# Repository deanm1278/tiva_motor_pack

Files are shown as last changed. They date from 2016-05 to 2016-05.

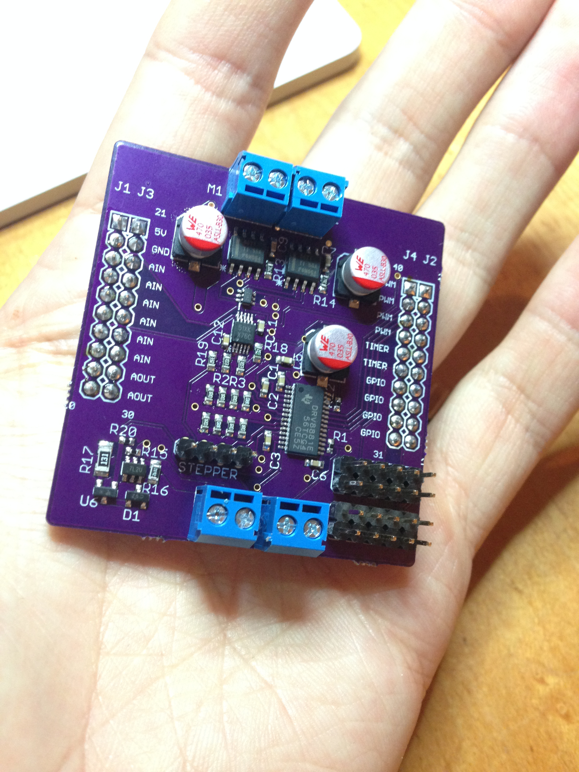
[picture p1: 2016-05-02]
tiva_motor.jpg

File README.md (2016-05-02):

# tiva_motor_pack
3 axis (2 servo 1 stepper) motor booster pack for EK-TM4C123GXL launchpad board

This booster pack drives 2 servos with encoders and 1 stepper motor.

The resolution limits are not yet well tested, but it definitely runs 2 brushed dc servos at 10khz velocity sampling and 1 stepper at 1/256 microstepping very smoothly. Stepper tested is a NEMA 17 2.0A at 2.8V motor that runs very smooth when microstepped. Servos tested are Harmonic drive RH-8 motors with Tamagawa encoders and also run well.

The software libraries include PID contol for the servos. Further tuning of PID may be necessary.

Servo drivers are TI DRV8871 (datasheet here: http://www.ti.com/lit/ds/symlink/drv8871.pdf)
stepper driver is a TI DRV8881E (datasheet here: http://www.ti.com/lit/ds/symlink/drv8881.pdf)

Autotune feature on the DRV8881E seems to work quite nicely :)

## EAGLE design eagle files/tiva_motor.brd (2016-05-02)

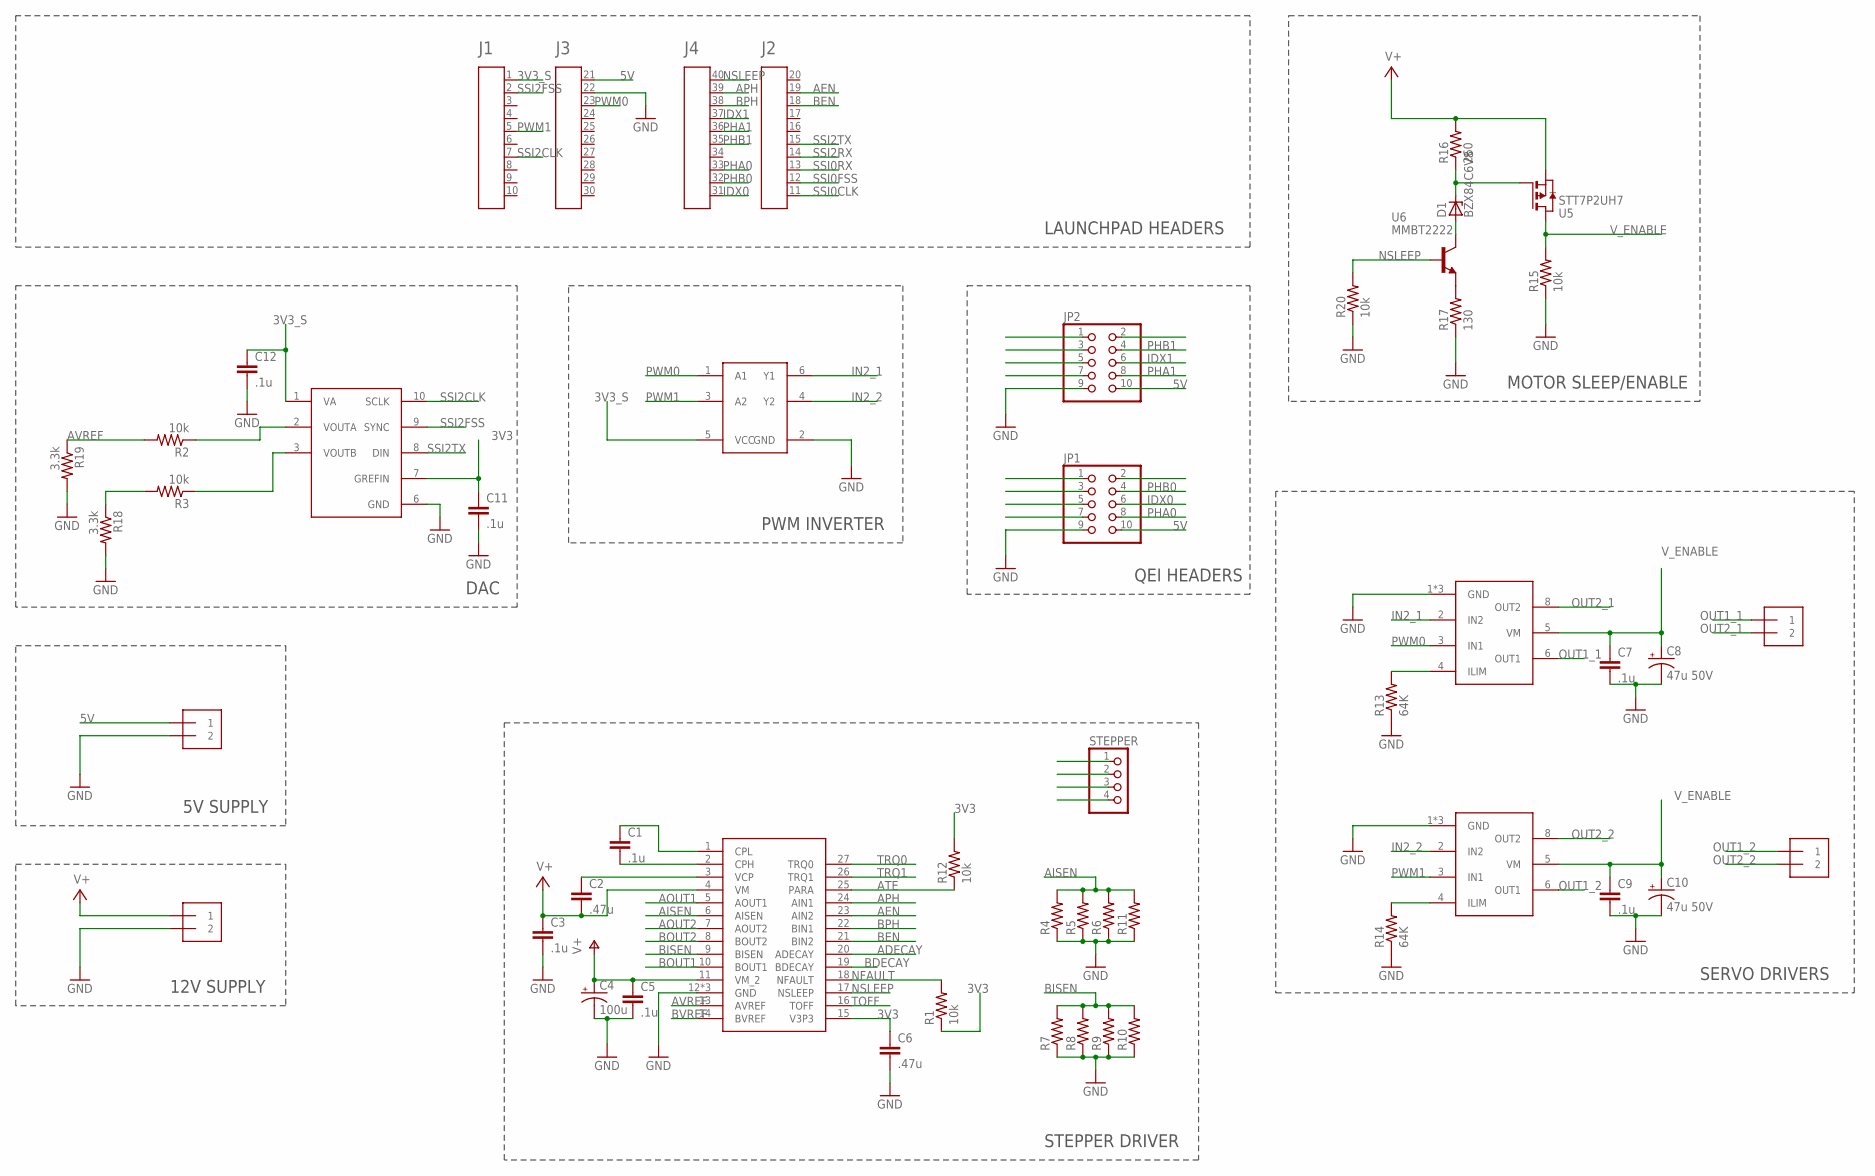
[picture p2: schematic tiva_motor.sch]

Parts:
5V, 12V: 1X2-3.5MM
A1: HEADER4X10-BOOSTERPACK; 4X10-BOOSTERPACK
C1, C3, C5, C7, C9: .1u; C0603
C2, C6: .47u; C0603
C4: 100u; 153CLV-0605
C8, C10: 47u 50V; 153CLV-0605
C11, C12: .1u; C0402
D1: BZX84C6V8; SOT-23
JP1, JP2: PINHD-2X5; 2X05
M1, M2: 1X2-3.5MM
R1, R12, R15, R20: 10k; R0402
R2, R3: 10k; R0603
R4, R5, R6, R7, R8, R9, R10, R11: R-US_R0603; R0603
R13, R14: 64K; R0603
R16: 260; R0805
R17: 130; R1206
R18, R19: 3.3k; R0603
STEPPER: PINHD-1X4; 1X04
U1: DRV8881; TSSOP28
U2, U4: DRV8871; SOIC127P600X170-9N
U5: STT7P2UH7; SOT23-6
U6: MMBT2222; SOT-23
U8: DAC082S085; SOP50P490X110-10N
U9: NC7WZ14; SC70-6

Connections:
3V3: C6.1, C11.1, R1.1, R12.2, U1.15 (V3P3), U8.7 (GREFIN)
3V3_S: A1.1, C12.1, U8.1 (VA), U9.5 (VCC)
5V: 5V.1, A1.21, JP1.10, JP2.10
ADECAY: U1.20 (ADECAY)
AEN: A1.19, U1.23 (AIN2)
AISEN: R4.2, R5.2, R6.2, R11.2, U1.6 (AISEN)
AOUT1: STEPPER.1, U1.5 (AOUT1)
AOUT2: STEPPER.2, U1.7 (AOUT2)
APH: A1.39, U1.24 (AIN1)
ATE: R12.1, U1.25 (PARA)
AVREF: R2.2, R19.1, U1.13 (AVREF)
BDECAY: U1.19 (BDECAY)
BEN: A1.18, U1.21 (BIN2)
BISEN: R7.2, R8.2, R9.2, R10.2, U1.9 (BISEN)
BOUT1: STEPPER.3, U1.10 (BOUT1)
BOUT2: STEPPER.4, U1.8 (BOUT2)
BPH: A1.38, U1.22 (BIN1)
BVREF: R3.2, R18.1, U1.14 (BVREF)
GND: 5V.2, 12V.2, A1.22, C3.2, C4.-, C5.2, C6.2, C7.2, C8.-, C9.2, C10.-, C11.2, C12.2, JP1.9, JP2.9, R4.1, R5.1, R6.1, R7.1, R8.1, R9.1, R10.1, R11.1, R13.1, R14.1, R15.1, R17.1, R18.2, R19.2, R20.1, U1.12 (GND), U1.28 (GND), U1.P$1 (GND), U2.1 (GND), U2.7 (GND), U2.9 (GND), U4.1 (GND), U4.7 (GND), U4.9 (GND), U8.6 (GND), U9.2 (GND)
IDX0: A1.31, JP1.6
IDX1: A1.37, JP2.6
ILIM: R13.2, U2.4 (ILIM)
ILIM1: R14.2, U4.4 (ILIM)
IN2_1: U2.2 (IN2), U9.6 (Y1)
IN2_2: U4.2 (IN2), U9.4 (Y2)
unnamed: C1.2, U1.2 (CPH)
unnamed: C1.1, U1.1 (CPL)
unnamed: C2.1, U1.3 (VCP)
unnamed: R17.2, U6.2 (E)
unnamed: D1.3 (C), R16.1, U5.3 (G)
unnamed: R2.1, U8.2 (VOUTA)
unnamed: R3.1, U8.3 (VOUTB)
unnamed: D1.1 (A), U6.3 (C)
NC: JP1.2
NFAULT: R1.2, U1.18 (NFAULT)
NSLEEP: A1.40, R20.2, U1.17 (NSLEEP), U6.1 (B)
OUT1_1: M1.1, U2.6 (OUT1)
OUT1_2: M2.1, U4.6 (OUT1)
OUT2_1: M1.2, U2.8 (OUT2)
OUT2_2: M2.2, U4.8 (OUT2)
PHA0: A1.33, JP1.8
PHA1: A1.36, JP2.8
PHB0: A1.32, JP1.4
PHB1: A1.35, JP2.4
PWM0: A1.23, U2.3 (IN1), U9.1 (A1)
PWM1: A1.5, U4.3 (IN1), U9.3 (A2)
SSI0CLK: A1.11
SSI0FSS: A1.12
SSI0RX: A1.13
SSI2CLK: A1.7, U8.10 (SCLK)
SSI2FSS: A1.2, U8.9 (SYNC)
SSI2RX: A1.14
SSI2TX: A1.15, U8.8 (DIN)
TOFF: U1.16 (TOFF)
TRQ0: U1.27 (TRQ0)
TRQ1: U1.26 (TRQ1)
V+: 12V.1, C2.2, C3.1, C4.+, C5.1, R16.2, U1.4 (VM), U1.11 (VM_2), U5.4 (S)
V_ENABLE: C7.1, C8.+, C9.1, C10.+, R15.2, U2.5 (VM), U4.5 (VM), U5.1 (D), U5.2 (D), U5.5 (D), U5.6 (D)

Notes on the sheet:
LAUNCHPAD HEADERS
DAC
5V SUPPLY
12V SUPPLY
PWM INVERTER
QEI HEADERS
MOTOR SLEEP/ENABLE
SERVO DRIVERS
STEPPER DRIVER

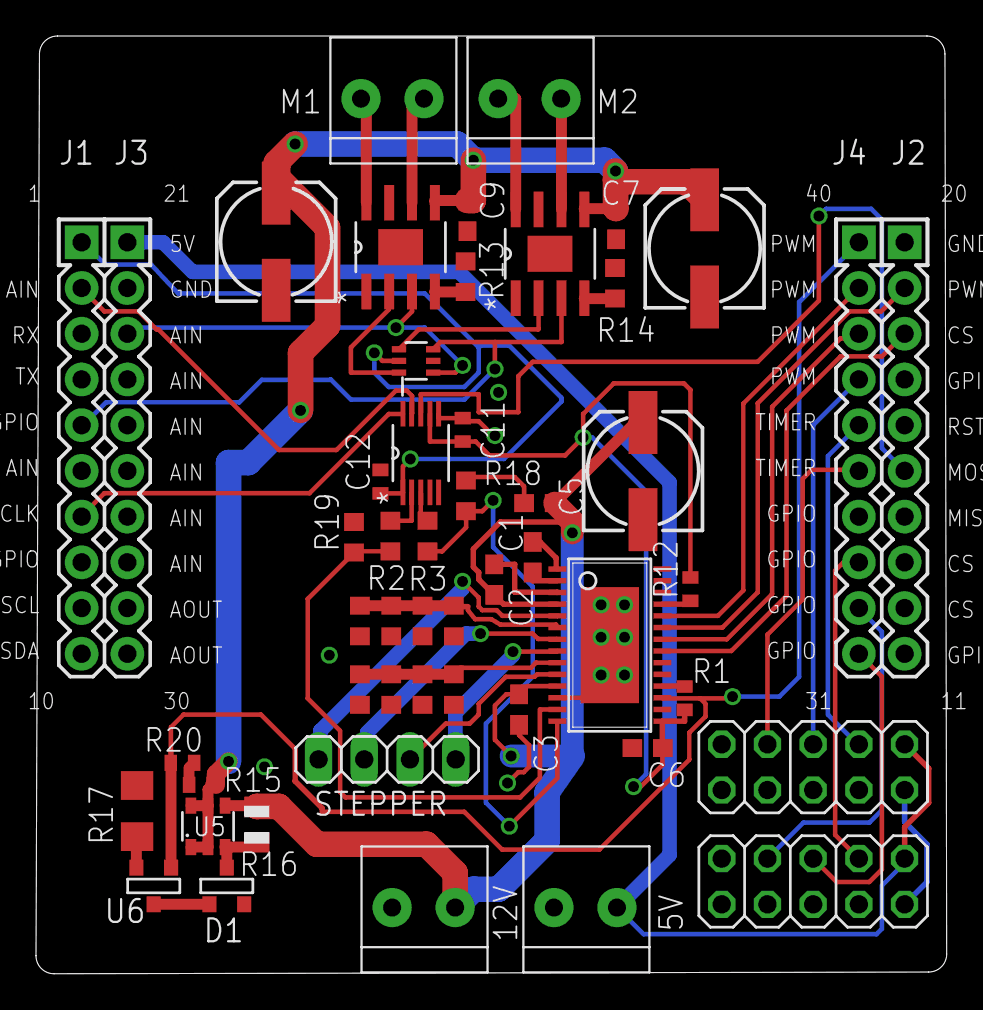
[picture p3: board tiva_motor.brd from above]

Board: 2 copper layers, 50.6 x 52.1 mm, 48 parts (0 on the bottom side), 48 nets.

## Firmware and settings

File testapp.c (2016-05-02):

#include <stdio.h>
#include <stdint.h>
#include <stdbool.h>

#include "inc/hw_memmap.h"

#include "driverlib/pin_map.h"
#include "driverlib/rom.h"
#include "driverlib/sysctl.h"

#include "libmotorpack/libmotorpack.h"

#define STEPS_PER_REV 200
#define SEC_PER_MIN 60

int main(void) {
	//
	// Enable lazy stacking for interrupt handlers.  This allows floating-point
	// instructions to be used within interrupt handlers, but at the expense of
	// extra stack usage.
	//
	ROM_FPULazyStackingEnable();
	ROM_FPUEnable();

	//
	// Set the clocking to run directly from the crystal.
	// Clock to 80MHZ
	//
	ROM_SysCtlClockSet(SYSCTL_SYSDIV_2_5 | SYSCTL_USE_PLL | SYSCTL_XTAL_16MHZ |
					   SYSCTL_OSC_MAIN);

	ROM_IntMasterEnable();

	//initialize the motor pack
	motor_pack_init();

	//initialize the stepper
	motor_pack_init_stepper();

	//set stepper to 20 rpm
	uint32_t rpm = 20;
	motor_pack_set_stepping_rate(rpm * STEPS_PER_REV / SEC_PER_MIN);

	//set to different speeds
	motor_pack_set_servo_speed(MP_SERVO1, -2.6);
	motor_pack_set_servo_speed(MP_SERVO2, 3);

	//initialize both servos
	motor_pack_init_servo(MP_SERVO1 | MP_SERVO2);

	//enable all drivers
	motor_pack_enable_motors();

	//start all motors
	motor_pack_stepper_start();
	motor_pack_servo_start(MP_SERVO1 | MP_SERVO2);

	//loop forever
	while(1){
	}

	return 0;
}

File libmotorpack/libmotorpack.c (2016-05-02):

/*
 * libmotorpack.c
 *
 *  Created on: May 1, 2016
 *      Author: Dean Miller
 */
#include <stdint.h>
#include <stdbool.h>
#include <math.h>

#include "inc/hw_ints.h"
#include "inc/hw_memmap.h"

#include "driverlib/pin_map.h"
#include "driverlib/gpio.h"
#include "driverlib/sysctl.h"
#include "driverlib/timer.h"
#include "driverlib/interrupt.h"
#include "driverlib/qei.h"
#include "driverlib/pwm.h"

#include "libmotorpack.h"
#include "stepper.h"
#include "servo.h"
#include "microstep_values.h"

static struct motor_pack mp;

//Define the QEI timer interrupts
void QEI0IntHandler(void){
	QEIIntClear(QEI0_BASE, QEI_INTTIMER);
	servo_read(&mp.servo1);

	servo_loop(&mp.servo1);
}

void QEI1IntHandler(void){
	QEIIntClear(QEI1_BASE, QEI_INTTIMER);
	servo_read(&mp.servo2);

	servo_loop(&mp.servo2);
}

//stepper interrupt handler
void
TIMER2IntHandler(void){
	//
	// Clear the timer interrupt.
	//
	TimerIntClear(TIMER2_BASE, TIMER_TIMA_TIMEOUT);
	uint32_t val = microstep_values[mp.step.t_val];

	if(val & MS_APH)	GPIOPinWrite(GPIO_PORTF_BASE, GPIO_PIN_3, GPIO_PIN_3);
	else	GPIOPinWrite(GPIO_PORTF_BASE, GPIO_PIN_3, 0x00);

	if(val & MS_BPH)	GPIOPinWrite(GPIO_PORTB_BASE, GPIO_PIN_3, GPIO_PIN_3);
	else	GPIOPinWrite(GPIO_PORTB_BASE, GPIO_PIN_3, 0x00);

	DAC082S085_set_value(&mp.step.dac, DAC082S085_DAC0, (val & MS_AVREF) >> 8);
	DAC082S085_set_value(&mp.step.dac, DAC082S085_DAC1, (val & MS_BVREF));

	mp.step.t_val += mp.step.div;
	mp.step.fires_this_move++;
	if(mp.step.t_val > 1023) mp.step.t_val = 0;
}

void motor_pack_init(){
	SysCtlPeripheralEnable(SYSCTL_PERIPH_GPIOF);

	GPIOPinTypeGPIOOutput(GPIO_PORTF_BASE, GPIO_PIN_2); //enable / disable for motors
	servo_init_pwm(&mp.servo1, PWM_OUT_0, PWM_PERIOD);
	servo_stop(&mp.servo1);

	servo_init_pwm(&mp.servo2, PWM_OUT_4, PWM_PERIOD);
	servo_stop(&mp.servo2);
}

void motor_pack_init_servo(uint32_t SERVO){
	if(SERVO & MP_SERVO1){
		servo_init_qei(&mp.servo1, QEI0_BASE);
	}
	if(SERVO & MP_SERVO2){
		servo_init_qei(&mp.servo2, QEI1_BASE);
	}
}

void motor_pack_set_servo_speed(uint32_t SERVO, float speed){
	int dir = 1;
	if(speed < 0){
		dir = -1;
		speed = fabs(speed);
	}
	if(SERVO & MP_SERVO1){
		mp.servo1.target_dir = dir;
		mp.servo1.target_speed = speed;
	}
	if(SERVO & MP_SERVO2){
		mp.servo2.target_dir = dir;
		mp.servo2.target_speed = speed;
	}
}

void motor_pack_servo_start(uint32_t SERVO){
	if(SERVO & MP_SERVO1){
		servo_start(&mp.servo1);
	}
	if(SERVO & MP_SERVO2){
		servo_start(&mp.servo2);
	}
}

void motor_pack_servo_stop(uint32_t SERVO){
	if(SERVO & MP_SERVO1){
		servo_stop(&mp.servo1);
	}
	if(SERVO & MP_SERVO2){
		servo_stop(&mp.servo2);
	}
}

void motor_pack_enable_motors(){
	GPIOPinWrite(GPIO_PORTF_BASE, GPIO_PIN_2, GPIO_PIN_2);
}

void motor_pack_disable_motors(){
	GPIOPinWrite(GPIO_PORTF_BASE, GPIO_PIN_2, 0);
}

void motor_pack_init_stepper(){
	stepper_init(&mp.step);
}

void motor_pack_set_stepper_div(uint32_t div){
	mp.step.div = div;
}

void motor_pack_set_stepping_rate(uint32_t stepping_rate){
	stepper_set_stepping_rate(&mp.step, stepping_rate);
}

void motor_pack_stepper_start(){
	stepper_start(&mp.step);
}

void motor_pack_stepper_stop(){
	stepper_stop(&mp.step);
}

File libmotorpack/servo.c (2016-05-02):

/*
 * servo.c
 *
 *  Created on: Jan 23, 2016
 *      Author: deanmiller
 */
#include <stdint.h>
#include <stdbool.h>
#include <string.h>
#include <stdlib.h>
#include <math.h>

#include "inc/hw_ints.h"
#include "inc/hw_memmap.h"
#include "inc/hw_types.h"
#include "inc/hw_gpio.h"

#include "driverlib/debug.h"
#include "driverlib/fpu.h"
#include "driverlib/gpio.h"
#include "driverlib/interrupt.h"
#include "driverlib/pin_map.h"
#include "driverlib/sysctl.h"
#include "driverlib/pwm.h"
#include "driverlib/qei.h"

#include "servo.h"
#include "pid.h"

extern void QEI0IntHandler(void);
extern void QEI1IntHandler(void);

void servo_init_pwm(struct servo *servo, uint32_t PWM_OUT, uint32_t PERIOD_HIGH)
{
	//TODO: make sure valid pwm base is passed in

	servo->PWM_PERIOD_HIGH = PERIOD_HIGH;
	servo->dc = PERIOD_HIGH / 2;
	servo->PWM_BASE = PWM0_BASE;
	servo->PWM_OUT = PWM_OUT;

	//set pwm clock to system clock
	SysCtlPWMClockSet(SYSCTL_PWMDIV_1);

	//already enabled
	SysCtlPeripheralEnable(SYSCTL_PERIPH_GPIOB);
	SysCtlPeripheralEnable(SYSCTL_PERIPH_GPIOE);

	SysCtlPeripheralEnable(SYSCTL_PERIPH_PWM0);
	//wait for peripheral to be ready
	while(!SysCtlPeripheralReady(SYSCTL_PERIPH_PWM0)){ }

	if(PWM_OUT == PWM_OUT_0){
		//configure for count down mode with immediate updates to params
		PWMGenConfigure(PWM0_BASE, PWM_GEN_0, PWM_GEN_MODE_DOWN | PWM_GEN_MODE_NO_SYNC);

		//set period
		PWMGenPeriodSet(PWM0_BASE, PWM_GEN_0, PWM_PERIOD);

		GPIOPinConfigure(GPIO_PB6_M0PWM0);

		GPIOPinTypePWM(GPIO_PORTB_BASE, GPIO_PIN_6);

		//enable outputs
		PWMOutputState(PWM0_BASE, PWM_OUT_0_BIT, true);

		//start timers in gen0
		PWMGenEnable(PWM0_BASE, PWM_GEN_0);
	}
	else if(PWM_OUT == PWM_OUT_4){
		//configure for count down mode with immediate updates to params
		PWMGenConfigure(PWM0_BASE, PWM_GEN_2, PWM_GEN_MODE_DOWN | PWM_GEN_MODE_NO_SYNC);

		//set period
		PWMGenPeriodSet(PWM0_BASE, PWM_GEN_2, PWM_PERIOD);

		GPIOPinConfigure(GPIO_PE4_M0PWM4);

		GPIOPinTypePWM(GPIO_PORTE_BASE, GPIO_PIN_4);

		//enable outputs
		PWMOutputState(PWM0_BASE, PWM_OUT_4_BIT, true);

		//start timers in gen2
		PWMGenEnable(PWM0_BASE, PWM_GEN_2);
	}

}

void servo_read(struct servo *servo)
{
	uint32_t i, sum = 0;
	servo->buf[servo->head] = QEIVelocityGet(servo->QEI_BASE);
	for(i=0; i<NUM_SPEED_SAMPLES; i++){
		sum += servo->buf[i];
	}
	servo->head++;
	if(servo->head == NUM_SPEED_SAMPLES){
		servo->head = 0;
	}
	servo->speed = (float)sum / NUM_SPEED_SAMPLES;
	servo->pos = QEIPositionGet(servo->QEI_BASE);
	servo->dir = QEIDirectionGet(servo->QEI_BASE);
	//TODO: handle overflow
}

void servo_loop(struct servo *servo)
{
	servo->dc += PIDcal(servo->target_speed * servo->target_dir, servo->speed * servo->dir, servo->target_pos, servo->pos, &servo->pid);
	if(servo->dc > PWM_PERIOD) servo->dc = PWM_PERIOD;
	else if(servo->dc < 0) servo->dc = 0;
	PWMPulseWidthSet(servo->PWM_BASE, servo->PWM_OUT, servo->dc);
}

void servo_init_qei(struct servo *servo, uint32_t QEI_BASE)
{
	//TODO: make sure valid qei base is passed in

	servo->QEI_BASE = QEI_BASE;

	PIDInit(&servo->pid);
	if(QEI_BASE == QEI0_BASE){
		//initialize qei 0
		SysCtlPeripheralEnable(SYSCTL_PERIPH_GPIOD);
		SysCtlPeripheralEnable(SYSCTL_PERIPH_QEI0);

		//Unlock GPIOD7 - Like PF0 its used for NMI - Without this step it doesn't work
		HWREG(GPIO_PORTD_BASE + GPIO_O_LOCK) = GPIO_LOCK_KEY; //In Tiva include this is the same as "_DD" in older versions (0x4C4F434B)
		HWREG(GPIO_PORTD_BASE + GPIO_O_CR) |= 0x80;
		HWREG(GPIO_PORTD_BASE + GPIO_O_LOCK) = 0;

		//Set Pins to be PHA0 and PHB0
		GPIOPinConfigure(GPIO_PD6_PHA0);
		GPIOPinConfigure(GPIO_PD7_PHB0);

		//Set GPIO pins for QEI. PhA0 -> PD6, PhB0 ->PD7. I believe this sets the pull up and makes them inputs
		GPIOPinTypeQEI(GPIO_PORTD_BASE, GPIO_PIN_6 | GPIO_PIN_7);

		//DISable peripheral and int before configuration
		QEIDisable(QEI0_BASE);
		QEIIntDisable(QEI0_BASE, QEI_INTERROR | QEI_INTDIR | QEI_INTTIMER | QEI_INTINDEX);

		//set max to largest 32 bit int
		QEIConfigure(QEI0_BASE, (QEI_CONFIG_CAPTURE_A_B  | QEI_CONFIG_NO_RESET |
		QEI_CONFIG_QUADRATURE | QEI_CONFIG_NO_SWAP), 4294967296 - 1);

		QEIVelocityConfigure(QEI0_BASE, QEI_VELDIV_1, SysCtlClockGet()/VEL_SAMPLE_PERIOD);
		QEIVelocityEnable(QEI0_BASE);

		QEIIntRegister(QEI0_BASE, QEI0IntHandler);
		// Enable the quadrature encoder.
		QEIEnable(QEI0_BASE);
		QEIPositionSet(QEI0_BASE, 0);
	}
	else if(QEI_BASE == QEI1_BASE){
		SysCtlPeripheralEnable(SYSCTL_PERIPH_GPIOC);
		SysCtlPeripheralEnable(SYSCTL_PERIPH_QEI1);

		//Set Pins to be PHA0 and PHB0

		GPIOPinConfigure(GPIO_PC5_PHA1);
		GPIOPinConfigure(GPIO_PC6_PHB1);

		GPIOPinTypeQEI(GPIO_PORTC_BASE, GPIO_PIN_5 | GPIO_PIN_6);

		//set max to largest 32 bit int
		QEIConfigure(QEI1_BASE, (QEI_CONFIG_CAPTURE_A_B  | QEI_CONFIG_NO_RESET |
		QEI_CONFIG_QUADRATURE | QEI_CONFIG_NO_SWAP), 4294967296 - 1);

		QEIFilterConfigure(QEI1_BASE, QEI_FILTCNT_2);
		QEIFilterEnable(QEI1_BASE);

		//enable velocity capture
		QEIVelocityConfigure(QEI1_BASE, QEI_VELDIV_1, SysCtlClockGet()/VEL_SAMPLE_PERIOD);
		QEIVelocityEnable(QEI1_BASE);

		QEIIntRegister(QEI1_BASE, QEI1IntHandler);
		//GPIOPadConfigSet(GPIO_PORTC_BASE, GPIO_PIN_5 | GPIO_PIN_6, GPIO_STRENGTH_8MA_SC, GPIO_PIN_TYPE_STD_WPU);
		//
		// Enable the quadrature encoder.
		//
		QEIEnable(QEI1_BASE);
		QEIPositionSet(QEI1_BASE, 0);
	}
}

void servo_stop(struct servo *servo){
	QEIIntDisable(servo->QEI_BASE, QEI_INTTIMER);
	servo->dc = servo->PWM_PERIOD_HIGH/2;
	PWMPulseWidthSet(servo->PWM_BASE, servo->PWM_OUT, servo->dc);
	servo->target_speed = 0;
}

void servo_start(struct servo *servo){
	QEIIntEnable(servo->QEI_BASE, QEI_INTTIMER);
}
